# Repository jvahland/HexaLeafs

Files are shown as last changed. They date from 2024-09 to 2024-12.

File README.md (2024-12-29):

# HexaLeafs

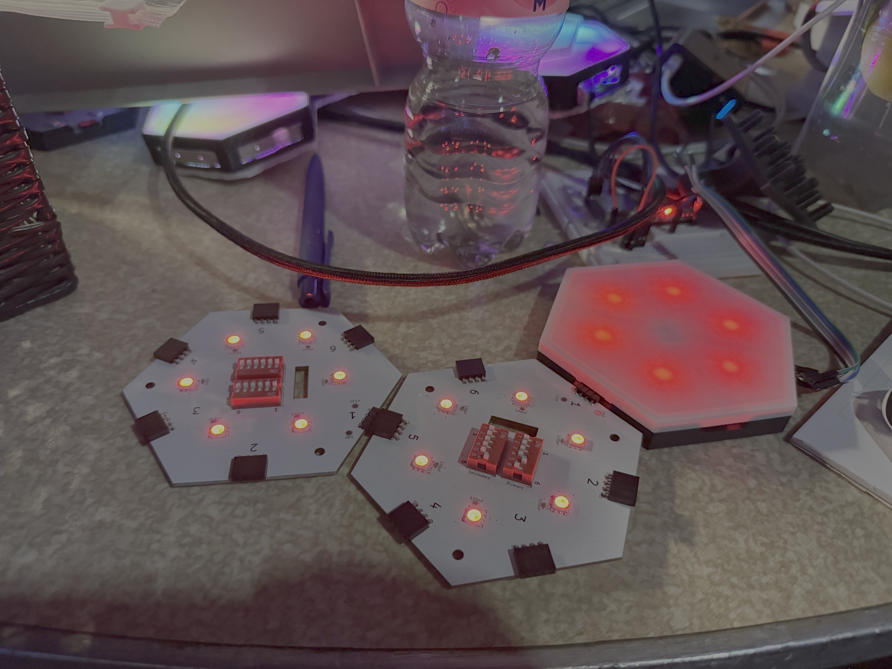
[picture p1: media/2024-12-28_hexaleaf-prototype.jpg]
hexaleaf prototype


## Description

We like hexagons and blinky lights.
So we thought, why not combine the two?

So we created a PCB in the shape of a hexagon with 6 LEDs on it.
The LEDs are controlled by wled, so you can control them via wifi.

## Design Records

There are many ways to design such a PCB.

We asked ourselves some questions and answered them with the following design decisions:

### Why hexagon?

Hexagons are bestagon ;)

### How To Connect The HexaLeafs With Each Other?

Here we had a lot discussions.

There were many ideas like pogo pins with magnets, spring loaded connectors, or even a custom connector with an extra PCB similar to Nanoleafs.

We asked ourselves what will be the typical use case for this PCB.
We came to the conclusion that the typical use case will be to put them on a wall or a ceiling and that the pattern of the connected PCBs will not change very often.

The connection should be easy to use and easy to connect and disconnect.

We also wanted to keep the cost low.
So we decided to use a simple 4-pin connector with a pitch of 2.54mm which are SMD soldered to the PCB.

### How To Power The HexaLeafs?

We decided to use a USB-C connector for power.
USB-C is a widely used standard and can deliver enough power for the LEDs.

### Which LEDs To Use?

We decided to use WS2815E LEDs.
They are similar to the well known WS2812 LEDs but have a higher voltage of 12V instead of 5V which makes them more suitable for longer LED strips.
The higher voltage also means that the current is lower which makes it easier to design the PCB.

### Area of One HexaLeaf?

The edge length of one HexaLeaf is 52mm.
The area of one HexaLeaf is 7025.198mm^2 = 0.007025198 m^2 (square meters).

10 Hexaleafs = 60 LEDs, they consume at 12V at full white brightness 0.25A in total.
The power consumption of 10 HexaLeafs is 3W.

Power Delivery of USB-C at 12V can be up to 60W.

-> 200 HexaLeafs can be powered by one USB-C port.
Which is 1.40504 m^4 (meters to the fourth) of LED area.

Standby is 0.102A, all LEDs off. TODO: Make a relais to switch off the power supply for the LEDs.
Nice to have feature! Not mandatory.

## Open Questions

### How To Mount The HexaLeafs To The Wall?

### Foo

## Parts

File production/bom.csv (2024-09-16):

Designator | Footprint | Quantity | Value | LCSC Part #
WS2815_6, WS2815_5, WS2815_4, WS2815_3, WS2815_2, WS2815 | LED_RGB_5050-6 | 6 | ~ | C4154879
100nF_6, 100nF_5, 100nF_4, 100nF_3, 100nF_2, 100nF | 0603 | 6 | 100n | C14663
J1 | PinHeader_1x04_P2.54mm_Horizontal | 1 | Conn_01x04 | C19190478
J2, J3, J4, J5, J6 | PinSocket_1x04_P2.54mm_Horizontal | 5 | Conn_01x04 | C2897386
Primary, Secondary | SW_DIP_SPSTx06_Slide_9.78x17.42mm_W7.62mm_P2.54mm | 2 | SW_DIP_x06 | C5299507

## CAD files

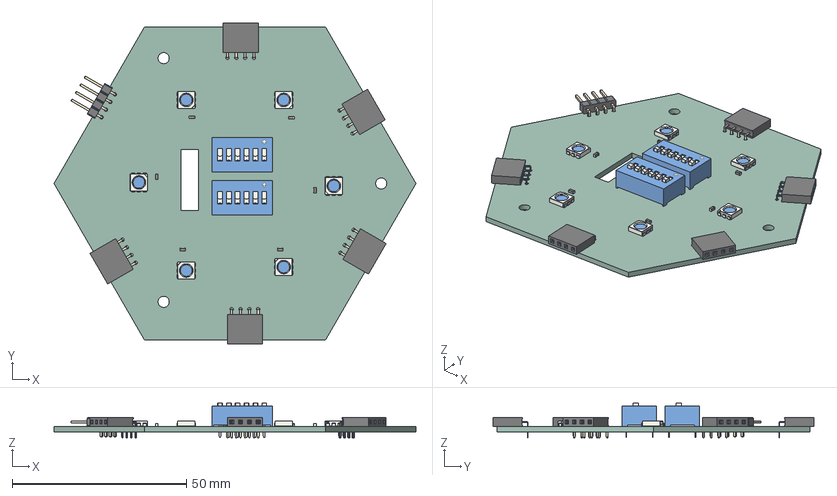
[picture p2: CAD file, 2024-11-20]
HexaLeafs.step
104.0 x 92.3 x 10.1 mm
C_0603_1608Metric x 6
PinHeader_1x04_P254mm_Horizontal
PinSocket_1x04_P254mm_Horizontal x 5
SW_DIP_SPSTx06_Slide_978x1742mm_W762mm_P254mm x 2
LED_RGB_5050_6 x 6
HexaLeafs_PCB

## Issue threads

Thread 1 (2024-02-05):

Routing of data lines and ground pour

jvahland, 2024-02-05:
Only do ground pour - limit power to wide traces.
Data lines should be routed in ground plane

hf-krechan, 2024-02-09:
I do not totally get the idea.
If the ground layer should be pour than there shouldn't be any data lines ^^

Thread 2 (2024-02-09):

Improve Layout Of Connectors To Increase Space For Cases

hf-krechan, 2024-02-09:
At the moment there is not enough distance between two pcbs.
To increase the distance the connectors should get placed closer to the edge.

hf-krechan, 2024-09-12:
Fixed in d15aa5cf31138aed8779553925a9ecf5a611557c

Closed 2024-09-12.

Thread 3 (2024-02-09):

Add Mounting Holes

hf-krechan, 2024-02-09:
We have three todos

- [ ] add mounting holes to easily mount the pcb inside a 3D printed case
- [x] add mounting holes so you can easily screw one hexagon to the wall
- [x] add a small slit so you can also use power stripes to clue the hexagon to a wall without seeing one end of the stripe.

hf-krechan, 2024-09-12:
The 3D print will not use the mounting holes.
We will try to design a case which has a clipping mechanism to hold the PCB.

hf-krechan, 2024-09-12:
Added mounting holes and small slit in d15aa5cf31138aed8779553925a9ecf5a611557c

Closed 2024-09-12.

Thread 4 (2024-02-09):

Twist in the data line

hf-krechan, 2024-02-09:
In the current PCB design there is a twist in the dataline.
This must get fixed so that you can connect multiple hexaleafs with each other.

hf-krechan, 2024-09-12:
Fixed

Closed 2024-09-12.

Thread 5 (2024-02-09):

Long Y Pattern Issue

hf-krechan, 2024-02-09:
The current pcb layout does not allow to route the data signal straight through a hexaleaf and than back again straight.

We will try to use two dip switches with different colours.
So you can choose with the first dip switch where the signal will first leave the hexagon.
And if it comes back to the same hexagon, you can choose with the second dip switch where it finally should leave.

hf-krechan, 2024-09-12:
Fixed

Closed 2024-09-12.

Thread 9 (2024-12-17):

Change kind of connection to be able to use magnets for nice snapping connection

hf-krechan, 2024-12-17:

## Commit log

2024-09-12 Reworked Layout and added 2nd DIP Switch for optional return path. Added mounting and Tesa Strip cutouts
    [HexaLeafs.kicad_pcb, HexaLeafs.kicad_sch]
2024-09-16 Addes Part details from LCSC for Assembly. Added Production files for JLCPCB
    [HexaLeafs.kicad_pcb, HexaLeafs.kicad_sch, bom.csv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]
2024-11-20 small trace alignments
    [HexaLeafs.kicad_pcb]
2024-11-20 align female connectores
    [HexaLeafs.kicad_pcb]
2024-11-20 Align male connector
    [HexaLeafs.kicad_pcb]
2024-11-20 save step file
    [HexaLeafs.step]
2024-11-20 Corrected Plug assignment
    [HexaLeafs.kicad_pcb]
2024-11-20 Align Traces and Connectors
    [HexaLeafs.kicad_pcb]
2024-12-29 Add README (#11)
    * first readme
    * add picture of prototype
    * add image to readme
    * replace png with jpg
    * use jpg
    * add original photo
    * add macOS related files to gitignore
    * Add infos how to power and and area calculation
